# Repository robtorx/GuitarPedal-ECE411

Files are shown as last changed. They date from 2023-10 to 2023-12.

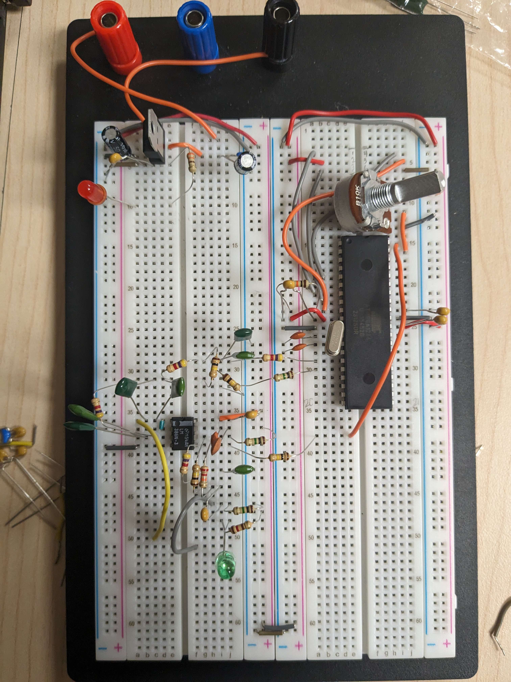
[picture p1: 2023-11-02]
Breadboard_Prototype_WIP.jpg

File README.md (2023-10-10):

# coolproject
ECE 411 - Fall 2023 - Team 12

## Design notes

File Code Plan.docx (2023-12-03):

High Level

Basic Operation: The program uses TIMER1 interrupts to initiate each ADC conversion manually, which allows for better control over the sample rate.

Setup Pins

- Set PD1 and PD2 as output pins.
- Set PA0 and PA1 as input pins.

Setup Timer1

- Initialize TIMER1 counter TCNT1 to 0x00.
- Set TIMER1 prescaler to 1 so TIMER1 = 16 MHz.
  - Frequency of timer interrupt = system clock frequency/(prescaler * compare match register value + 1)
- Timer operates in phase correct, PWM mode. TOP value is stored in ICR1, since OCR1A/B are used to control PWM output pins.
  - Set WGM13 to 1, WGM12 to 0, WGM11 to 1, WGM10 to 0.
- Maximize PWM frequency.
  - PWM frequency = timer
  - Write 0xFF to ICR1L.
  - Write 0xFF, shifted 8 bits to ICR1H.

Setup ADC

- Use AVCC as reference voltage -> Write 1 to ADMUX.REFS
- Left aligned for 8 bit resolution: write 1 to ADMUX.ADLAR
- Prescaler = 128 for 16 MHz clock
  - ADC operates from 50 KHz to 200 KHz to get maximum resolution
  - 16 MHz/128 = 125 KHz ADC frequency
  - Write 0x111 to ADCSRA.ADPS
- Initialize ADMUX.MUX to channel 0 (pin ADC0)
  - This will change periodically to channel 1 in order to read the potentiometer.
- IF FREE RUNNING MODE:
  - Enable ADC conversion complete interrupt.
    - Set ADCSRA.ADIE to 1.
  - Enable auto trigger.
    - Write 1 to ADCSRA.ADATE
- Enable ADC.
  - Set power reduction ADC bit (PRR.PRADC) to 0
  - Write 1 to ADCSR.ADEN.
    - Note: Takes 25 ADC clock cycles to initialize first conversion. After that, further conversions take 13 ADC clock cycles (13.5 for auto triggered conversions).
- Enable global interrupts.
- Start a single conversion.
  - Set start conversion bit to 1 in ADCSRA.ADCS.

Change Channels Function

- If ADMUX.MUX = 0 (ADC0 currently active)
  - Set ADMUX.MUX to 1.
- If ADMUX.MUX = 1
  - Set ADMUX.MUX to 0.

Interrupt Service: TIMER1

- Increment counter.
- If counter = n:
  - Switch ADC channels.
  - Reset counter = 0.
- If counter = 0:
  - Switch ADC channels
- Initiate ADC conversion.

Interrupt Service: ADC Complete

- POTENTIOMETER LOGIC: If counter = n (n to be found experimentally)
  - Read ADCH into POT. Leave ADCin unchanged.
  - Call change channels function again.
  - Reset counter = 0.
- Map upper and lower threshholds based on potentiometer value.
- Map input values to amplified equivalents.
- If (ADC value >= upper threshold)
  - Set output value = upper threshold
- If (ADC value <= lower threshold)
  - Set output value = lower threshold
- POTENTIOMETER LOGIC: If (++counter=n)
  - Call change channels function so next ADC interrupt will be for channel 1.
- Convert ADC_high and ADC_low into 16 bit value.
  - Write combined value to OCR1A/B.

https://onlinedocs.microchip.com/pr/GUID-F670183D-C025-46C7-B7F5-9BAD389BF43F-en-US-3/index.html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

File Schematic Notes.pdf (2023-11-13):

Input Buffer Stage
R2 and R3 form a non-inverting amplifier circuit that amplifies the guitar level (100-400 mV) to acceptable ADC level (5 V). This means the circuit gain has to be at most 5V/0.1V = 50 and at least 5V/0.4V = 12.5.
- A = 1 +

R2
R3 = 1 +

100k
4.7k = 22. 277
R2 and C8 form a low pass filter that allows all frequencies below 4823 Hz to pass. Additionally, R3 and C9 form a high pass filter that allows all frequencies above 34 Hz to pass. C7, R5 and R6 form another high pass filter that eliminates the DC component from the signal. These filters cut out unnecessary noise and frequencies that are harsh when amplified.
- f = 1/2πRC
R4 essentially becomes the input impedance of the signal chain, which is typically 1M Ohms for guitar pedals.

Output Buffer
2 PWM pins are used in order to double the bitrate of the output signal. If only one PWM signal is outputted by the ATMega, the output amplifier defaults to being a buffer.

Resistors R9, R10, capacitors C14, and C11 all form a 3rd order Sallen & Key low pass filter with a cutoff frequency at 5131 Hz.
- f = 1/(2π * R
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
Capacitor C12 eliminates any DC offset before outputting the final, processed signal.

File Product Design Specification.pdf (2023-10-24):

### Team 12 Product Design Specifications

Oct 18, 2023

Executive Summary with Concept of Operations
A guitar pedal takes an input signal from a guitar and modifies it with an effect before passing it on to the output chain (could be an amplifier). It’s used by guitarists to achieve different tones and effects. Our pedal is specifically a distortion pedal, which increases the signal’s gain to produce a gritty tone. The user is able to turn on and change the level of distortion using a foot pedal (button) and knobs.

Who are the intended customers / users?
Although we are designing this product with electric guitarists in mind, anyone who plays an instrument with a line signal could use this pedal. We are targeting the product towards those hoping to achieve different sounds or enhance their performance.

What is the competition? Why is your product different?
The competition is all custom guitar pedals. This includes companies like BOSS, Donner, Ibanez and Line 6. Additionally, there is a wide market and scene for smaller indie pedal producers, as well as DIY hobbyists.

In theory, what sets this pedal apart is the fact that it’s programmable, as opposed to most typical, purely analog pedals. This means you could add, layer or otherwise change the effect via software, allowing a variety of sounds within the same product. That said, we are choosing to focus on a distortion effect as our minimal requirement.

What price do you think you can sell this for, and why? (keep it short, we're engineers, not marketing researchers)
The cheapest end of popular pedals on the market are around $60, so we aim to keep our model below that, at around $40-$50 per unit. Having a relatively lower price means customers are more likely to risk buying a product from an unknown manufacturer like our team, over a more reputable brand like BOSS. This is our goal for at least the minimal distortion pedal; Should we achieve the programmable multi-effect goal, we could charge more for the novelty.

Product Requirements
Must:
- Must distort the input signal in some way.
- Must be able to be toggled on/off.
- Must be durable enough to be operated by foot.
- Must not harm the user.
- Must be able to vary the level of the distortion effect. Should:
- Should not introduce significant noise when bypassed.

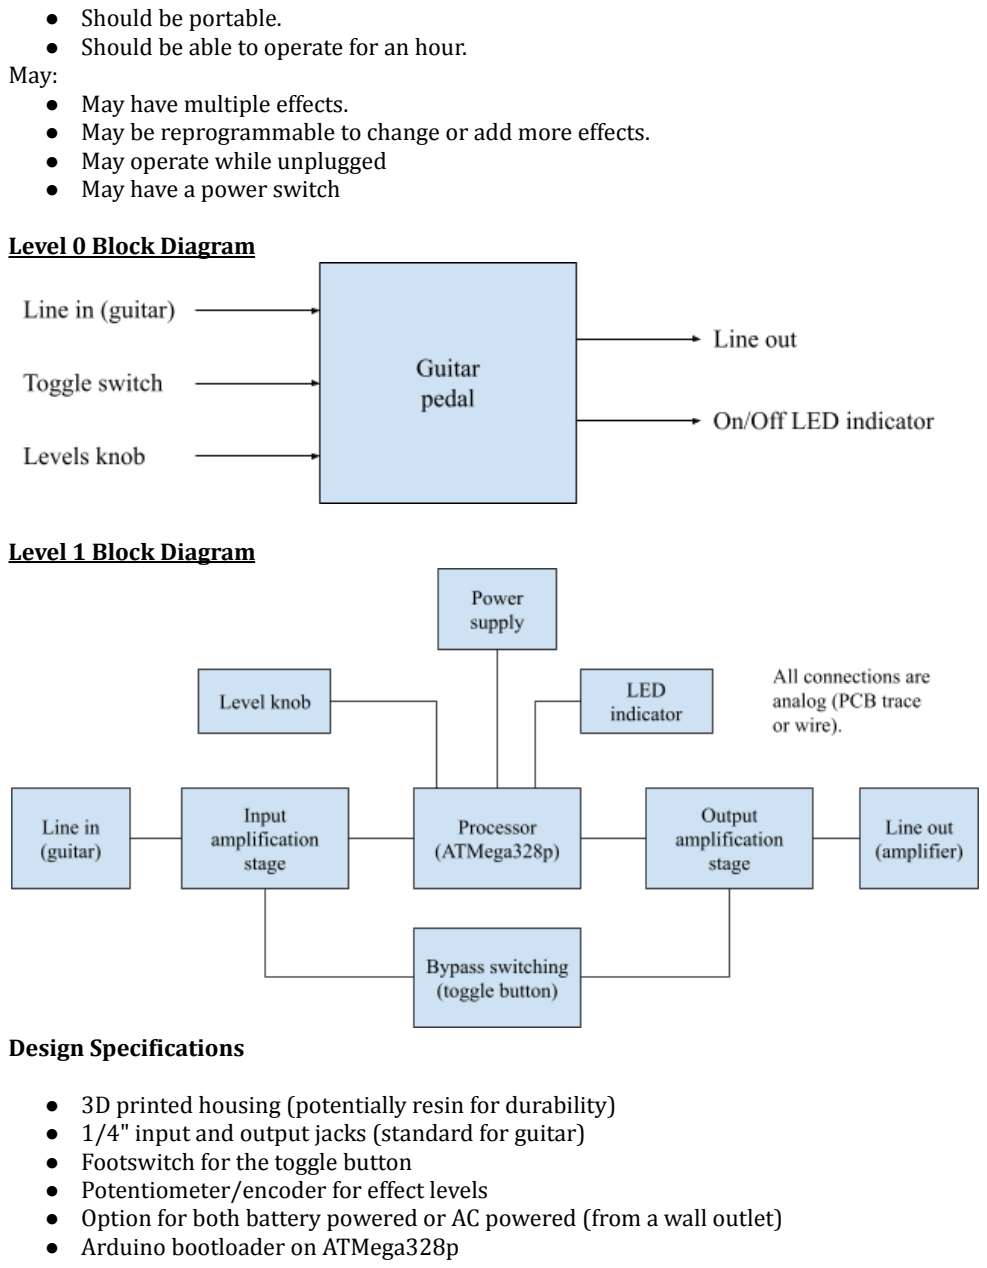
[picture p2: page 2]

- Should be portable.
- Should be able to operate for an hour.
May:
- May have multiple effects.
- May be reprogrammable to change or add more effects.
- May operate while unplugged
- May have a power switch

Level 0 Block Diagram

Level 1 Block Diagram

Design Specifications

- 3D printed housing (potentially resin for durability)
- 1/4" input and output jacks (standard for guitar)
- Footswitch for the toggle button
- Potentiometer/encoder for effect levels
- Option for both battery powered or AC powered (from a wall outlet)
- Arduino bootloader on ATMega328p

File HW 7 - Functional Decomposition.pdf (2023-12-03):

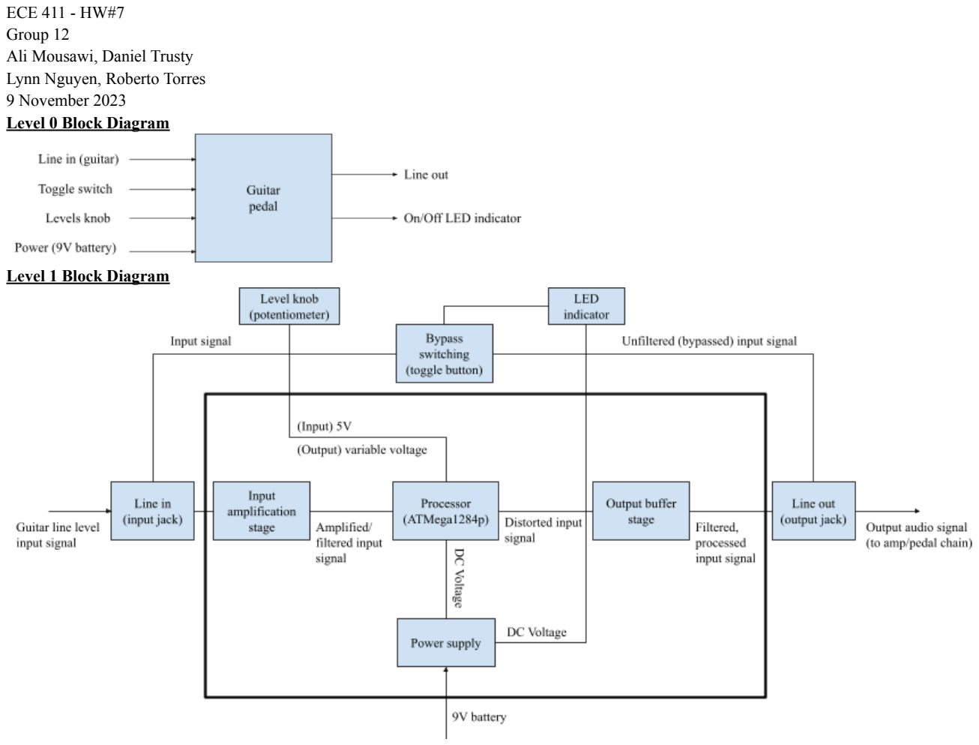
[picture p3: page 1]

ECE 411 - HW#7
Group 12
Ali Mousawi, Daniel Trusty Lynn Nguyen, Roberto Torres 9 November 2023
Level 0 Block Diagram

Level 1 Block Diagram

Submodules L1
Line In

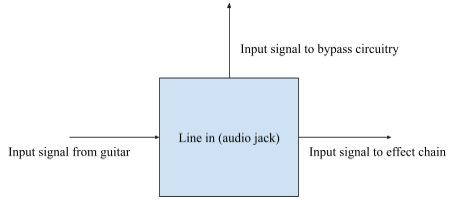
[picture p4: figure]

Module | Line in (audio jack)
Inputs | Audio signal from guitar (100 - 400 mV standard)
Outputs | Input signal to effect circuitry, input signal to bypass circuitry (100 - 400 mV)
Functionality | Accepts external audio source (from guitar)

Bypass Switch

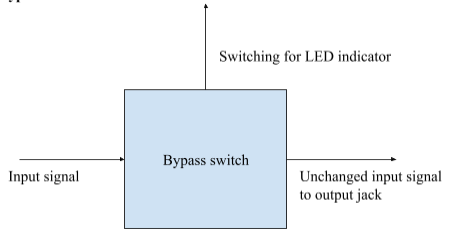
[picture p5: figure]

Module | Bypass circuitry
Inputs | Input signal from input jack
Outputs | Unprocessed input signal to output jack, switching circuitry for LED indicator
Functionality | Allows user the option of toggling the pedal effect, part of and controls user interface (LED)

LED indicator

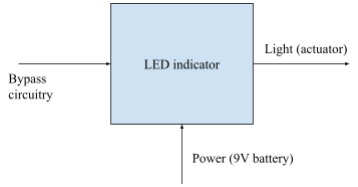
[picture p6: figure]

Module | LED indicator
Inputs | Bypass circuitry, power (9V battery)
Outputs | Light indication
Functionality | User interface, allows user to know if effect is on or off

Levels knob

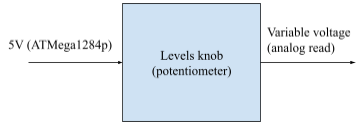
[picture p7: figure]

Module | Levels knob
Inputs | 5V (ATMega1284p)
Outputs | Variable voltage to ATMega1284p analog read
Functionality | User interface, used as a voltage sensor translated to variable levels in effect

Input amplification stage

Module | Input amplification stage
Inputs | Input audio signal (100-400 mV)
Outputs | Filtered/amplified audio signal (5 V)
Functionality | Amplifies signal to ATMega1284p ADC pin levels, cuts unnecessary noise through filtering

Processor

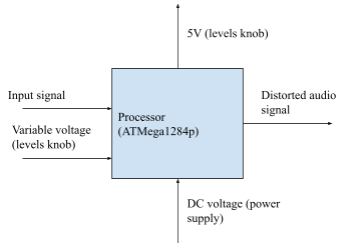
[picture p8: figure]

Module | Input amplification stage
Inputs | Input audio signal (5 V), variable voltage (from levels knob, analog read)
Outputs | Distorted audio signal, 5V for levels knob
Functionality | Performs digital processing on audio signal based on user inputs

Output buffer stage

Module | Output buffer stage
Inputs | Distorted audio signal (5 V)
Outputs | Filtered, distorted signal
Functionality | Further filters distorted signal to prepare for output

Line out

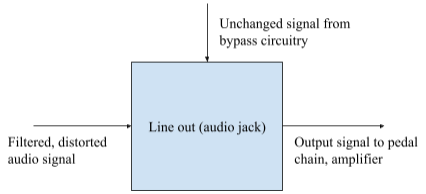
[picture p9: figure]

Module | Line in (audio jack)
Inputs | (Only one transmitting at once) unchanged signal from bypass circuitry, filtered/distorted audio signal
Outputs | Output signal to pedal chain or amplifier
Functionality | Transmits audio to external actuator (amplifier, pedal chain)

Line out

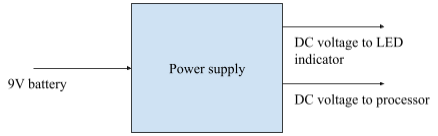
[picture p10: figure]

Module | Power supply
Inputs | 9V battery
Outputs | DC voltages
Functionality | Provides regulated power to all circuitry

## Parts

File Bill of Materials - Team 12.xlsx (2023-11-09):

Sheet: ECE411 BOM Template
Bill Of Materials for: T12
Last modified: 8 Nov 2023
PCB version: [PCB VERSION #]
BOM revision: [BOM REVISION #] |  | P/NP | = Place/Not Place (components marked NP are not stuffed on the board)
Cnt | Part References | P/NP | Mfg | Mfg PN | Description | Dist | Dist Part Number | Cost Ea. | Cost Total
1 | U1 | P | Microchip | ATmega1284-AU-ND | IC MCU 8BIT 128KB FLASH 44TQFP | Digi-Key | ATMEGA1284-AU-ND | $6.30 | $6.30
1 | U2 | P | ST | L7805ABV | IC Linear Voltage Regulator 5V 1.5A TO220AB | Digi-Key | 497-2947-5-ND | $0.75 | $0.75
1 | U3 | P | TI | TL972IDR | IC OPAMP GP 2 CIRCUIT 8SOIC | Digi-Key | 296-22842-1-ND - (CT) | $0.80 | $0.80
1 | Y1 | P | CTS Electronic Components | ATS16A | 16MHz 20pF Crystal Oscillator | Mouser | 774-ATS16A | $0.45 | $0.45
1 | RV1 | P | Swpeet | N/A | 10k Single Linear Rotary Potentiometer 3T WH148 and Knob | Amazon | B07ZKJVZ53 | $0.60 | $0.60
2 | J1, J2 | P | Neutrik | NMJ6HCD2 | 1/4" TRS Audio Jack | Mouser | 550-22302 | $2.29 | $4.58
1 | SW1 | P | DaierTek | KCD1-101 | SPST 2PIN Rocker Switch ON/OFF | Amazon | B07S2QJKTX | $0.80 | $0.80
1 | SW2 | P | ESUPPORT | CXGTS01A | 3PDT 9 Pins Metal Foot Switch True Bypass | Amazon | B012CF181K | $2.58 | $2.58
1 | D1 | P | Generic | N/A | RED LED 5MM | Digi-Key | 160-1827-ND | $0.07 | $0.07
1 | D2 | P | Generic | N/A | GREEN LED 5MM | Digi-Key | 1N4148FS-ND | $0.03 | $0.03
2 | C1, C2 | P | Walfront | N/A | 10uf SMD Electrolytic Capacitor | Amazon | ‎ B0793N3YJR | $0.07 | $0.14
4 | C10, C11, C12, C14 | P | MCIGICM | N/A | 6.8nF Ceramic Capacitor 1206 SMD | Amazon | B06XDHC93D | $0.03 | $0.12
1 | C3 | P | MCIGICM | N/A | 0.33uf Ceramic Capacitor 1206 SMD | Amazon | B06XDHC93D | $0.03 | $0.03
6 | C4, C7, C13, C15, C16, C17 | P | MCIGICM | N/A | 100NF 104M Y5V 50V ± 20% | Amazon | B06XDHC93D | $0.03 | $0.18
2 | C5, C6 | P | MCIGICM | N/A | 22PF 220J COG 50V ± 5% | Amazon | B06XDHC93D | $0.03 | $0.06
1 | C8 | P | MCIGICM | N/A | 270pf Ceramic Capacitor 1206 SMD | Amazon | B06XDHC93D | $0.03 | $0.03
1 | C9 | P | Walfront | N/A | 1uf SMD Electrolytic Capacitor | Amazon | ‎ B0793N3YJR | $0.07 | $0.07
1 | R1 | P | Chanzon | DZ-TPDZ1206B1-TC60-1200 | 330R Resistor 1206 SMD 1/4W 0.25W ±1% | Amazon | B08RYMYWG9 | $0.01 | $0.01
1 | R2 | P | Chanzon | DZ-TPDZ1206B1-TC60-1200 | 100k Resistor 1206 SMD 1/4W 0.25W ±1% | Amazon | B08RYMYWG9 | $0.01 | $0.01
4 | R3, R7, R9, R10 | P | Chanzon | DZ-TPDZ1206B1-TC60-1200 | 4.7k Resistor 1206 SMD 1/4W 0.25W ±1% | Amazon | B08RYMYWG9 | $0.01 | $0.04
2 | R4, R6 | P | Chanzon | DZ-TPDZ1206B1-TC60-1200 | 1M Resistor 1206 SMD 1/4W 0.25W ±1% | Amazon | B08RYMYWG9 | $0.01 | $0.02
1 | R5 | P | Chanzon | DZ-TPDZ1206B1-TC60-1200 | 18k Resistor 1206 SMD 1/4W 0.25W ±1% | Amazon | B08RYMYWG9 | $0.01 | $0.01
1 | R8 | P | Chanzon | DZ-TPDZ1206B1-TC60-1200 | 1M2 Resistor 1206 SMD 1/4W 0.25W ±1% | Amazon | B08RYMYWG9 | $0.01 | $0.01
1 | R11 | P | Chanzon | DZ-TPDZ1206B1-TC60-1200 | 120R Resistor 1206 SMD 1/4W 0.25W ±1% | Amazon | B08RYMYWG9 | $0.01 | $0.01
1 | R12 | P | Chanzon | DZ-TPDZ1206B1-TC60-1200 | 10k Resistor 1206 SMD 1/4W 0.25W ±1% | Amazon | B08RYMYWG9 | $0.01 | $0.01
1 | BT1 | NP | Generic | N/A | 9V Battery | Amazon | N/A | $1.50 | $1.50
1 | NA | P | Generic | N/A | 9V Battery Connector | Amazon | N/A | $0.50 | $0.50
6 | NA | P | Generic | N/A | Breakable Headers 2.54mm | Amazon | N/A | $0.01 | $0.03
 |  |  |  |  |  |  |  | TOTAL: | $19.74
VERSION INFO
Rev | Date | Notes
1 | 2023-11-09 | Inital BOM

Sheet: Copy of ECE411 BOM Template
Bill Of Materials for: T12
Last modified: 8 Nov 2023
PCB version: [PCB VERSION #]
BOM revision: [BOM REVISION #] |  | P/NP | = Place/Not Place (components marked NP are not stuffed on the board)
Cnt | Part References | P/NP | Mfg | Mfg PN | Description | Dist | Dist Part Number | Cost Ea. | Cost Total | Shipping Cost | Purchase Links
1 | U1 | P | Microchip | ATmega1284-AU-ND | IC MCU 8BIT 128KB FLASH 44TQFP | Digi-Key | ATMEGA1284-AU-ND | $6.30 | $6.30 | 6.99 | https://www.digikey.com/en/products/detail/microchip-technology/ATMEGA1284-AU/2271240
1 | U2 | P | ST | L7805ABV | IC Linear Voltage Regulator 5V 1.5A TO220AB | Digi-Key | 497-2947-5-ND | $0.75 | $0.75 | EPL | https://www.digikey.com/en/products/detail/stmicroelectronics/L7805ABV/634711
1 | U3 | P | TI | TL972IDR | IC OPAMP GP 2 CIRCUIT 8SOIC | Digi-Key | 296-22842-1-ND - (CT) | $0.80 | $0.80 | inc | https://www.digikey.com/en/products/detail/texas-instruments/TL972IDR/1739871
1 | Y1 | P | CTS Electronic Components | ATS16A | 16MHz 20pF Crystal Oscillator | Mouser | 774-ATS16A | $0.45 | $0.45 | inc | https://www.mouser.com/ProductDetail/774-ATS16A
1 | RV1 | P | Swpeet | N/A | 10k Single Linear Rotary Potentiometer 3T WH148 and Knob | Amazon | B07ZKJVZ53 | $0.60 | $0.60 | X | https://www.amazon.com/dp/B07ZKJVZ53
2 | J1, J2 | P | Neutrik | NMJ6HCD2 | 1/4" TRS Audio Jack | Mouser | 550-22302 | $2.29 | $4.58 | 7.99 | https://www.mouser.com/ProductDetail/550-22302
1 | SW1 | P | DaierTek | KCD1-101 | SPST 2PIN Rocker Switch ON/OFF | Amazon | B07S2QJKTX | $0.80 | $0.80 | X | https://www.amazon.com/dp/B07S2QJKTX
1 | SW2 | P | ESUPPORT | CXGTS01A | 3PDT 9 Pins Metal Foot Switch True Bypass | Amazon | B012CF181K | $2.58 | $2.58 |  | https://www.amazon.com/dp/B012CF181K
1 | D1 | P | Generic | N/A | RED LED 5MM | Digi-Key | 160-1827-ND | $0.07 | $0.07
1 | D2 | P | Generic | N/A | GREEN LED 5MM | Digi-Key | 1N4148FS-ND | $0.03 | $0.03
2 | C1, C2 | P | Walfront | N/A | 10uf SMD Electrolytic Capacitor | Amazon | ‎ B0793N3YJR | $0.07 | $0.14
4 | C10, C11, C12, C14 | P | MCIGICM | N/A | 6.8nF Ceramic Capacitor 1206 SMD | Amazon | B06XDHC93D | $0.03 | $0.12
1 | C3 | P | MCIGICM | N/A | 0.33uf Ceramic Capacitor 1206 SMD | Amazon | B06XDHC93D | $0.03 | $0.03
6 | C4, C7, C13, C15, C16, C17 | P | MCIGICM | N/A | 100NF 104M Y5V 50V ± 20% | Amazon | B06XDHC93D | $0.03 | $0.18
2 | C5, C6 | P | MCIGICM | N/A | 22PF 220J COG 50V ± 5% | Amazon | B06XDHC93D | $0.03 | $0.06
1 | C8 | P | MCIGICM | N/A | 270pf Ceramic Capacitor 1206 SMD | Amazon | B06XDHC93D | $0.03 | $0.03
1 | C9 | P | Walfront | N/A | 1uf SMD Electrolytic Capacitor | Amazon | ‎ B0793N3YJR | $0.07 | $0.07
1 | R1 | P | Chanzon | DZ-TPDZ1206B1-TC60-1200 | 330R Resistor 1206 SMD 1/4W 0.25W ±1% | Amazon | B08RYMYWG9 | $0.01 | $0.01
1 | R2 | P | Chanzon | DZ-TPDZ1206B1-TC60-1200 | 100k Resistor 1206 SMD 1/4W 0.25W ±1% | Amazon | B08RYMYWG9 | $0.01 | $0.01
4 | R3, R7, R9, R10 | P | Chanzon | DZ-TPDZ1206B1-TC60-1200 | 4.7k Resistor 1206 SMD 1/4W 0.25W ±1% | Amazon | B08RYMYWG9 | $0.01 | $0.04
2 | R4, R6 | P | Chanzon | DZ-TPDZ1206B1-TC60-1200 | 1M Resistor 1206 SMD 1/4W 0.25W ±1% | Amazon | B08RYMYWG9 | $0.01 | $0.02
1 | R5 | P | Chanzon | DZ-TPDZ1206B1-TC60-1200 | 18k Resistor 1206 SMD 1/4W 0.25W ±1% | Amazon | B08RYMYWG9 | $0.01 | $0.01
1 | R8 | P | Chanzon | DZ-TPDZ1206B1-TC60-1200 | 1M2 Resistor 1206 SMD 1/4W 0.25W ±1% | Amazon | B08RYMYWG9 | $0.01 | $0.01
1 | R11 | P | Chanzon | DZ-TPDZ1206B1-TC60-1200 | 120R Resistor 1206 SMD 1/4W 0.25W ±1% | Amazon | B08RYMYWG9 | $0.01 | $0.01
1 | R12 | P | Chanzon | DZ-TPDZ1206B1-TC60-1200 | 10k Resistor 1206 SMD 1/4W 0.25W ±1% | Amazon | B08RYMYWG9 | $0.01 | $0.01
1 | BT1 | NP | Generic | N/A | 9V Battery | Amazon | N/A | $1.50 | $1.50
1 | NA | P | Generic | N/A | 9V Battery Connector | Amazon | N/A | $0.50 | $0.50
6 | NA | P | Generic | N/A | Breakable Headers 2.54mm | Amazon | N/A | $0.01 | $0.03
 |  |  |  |  |  |  |  | TOTAL: | $19.74
VERSION INFO
Rev | Date | Notes
1 | 2023-11-09 | Inital BOM

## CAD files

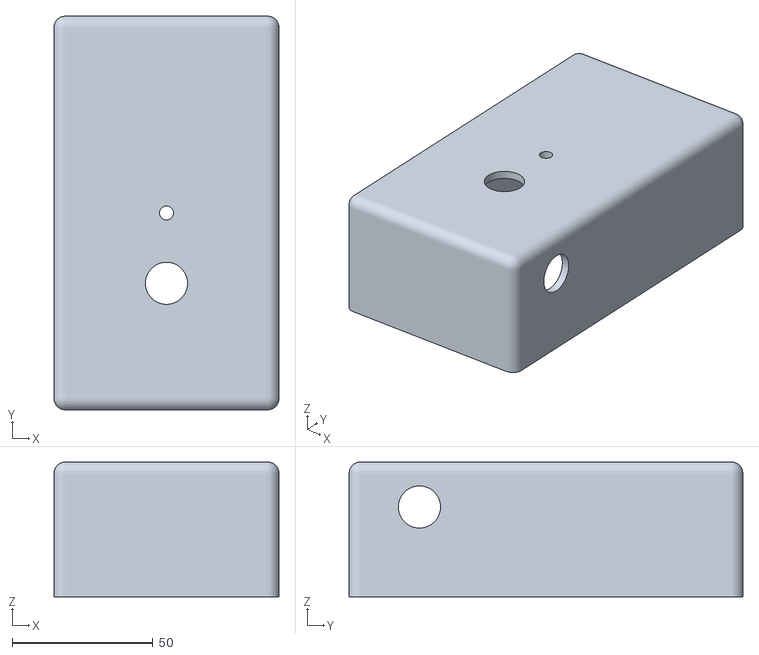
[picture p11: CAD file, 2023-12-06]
Fusion files/Upper housing v9.stl
80.0 x 140.0 x 48.0

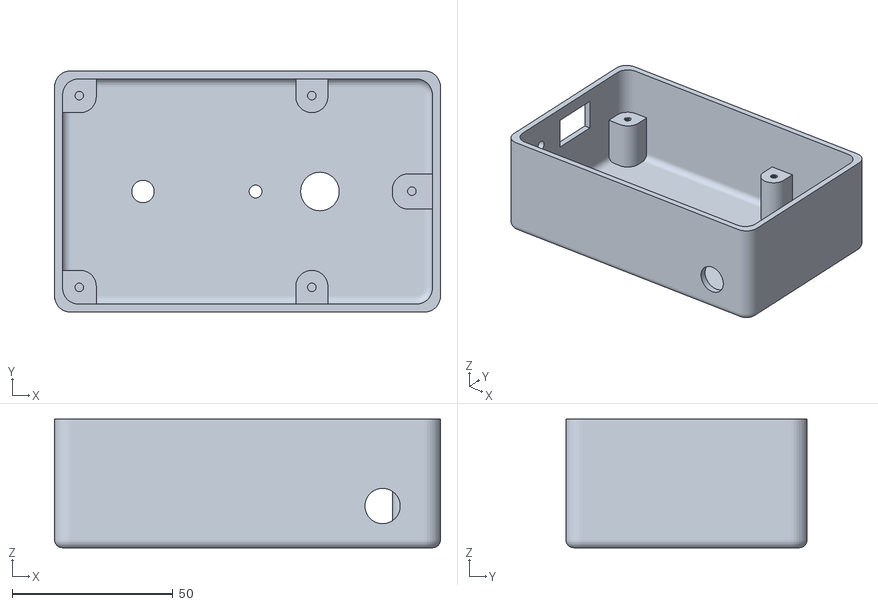
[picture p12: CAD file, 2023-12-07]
STL Files/UpperHousing v1.stl
120.0 x 75.0 x 40.0

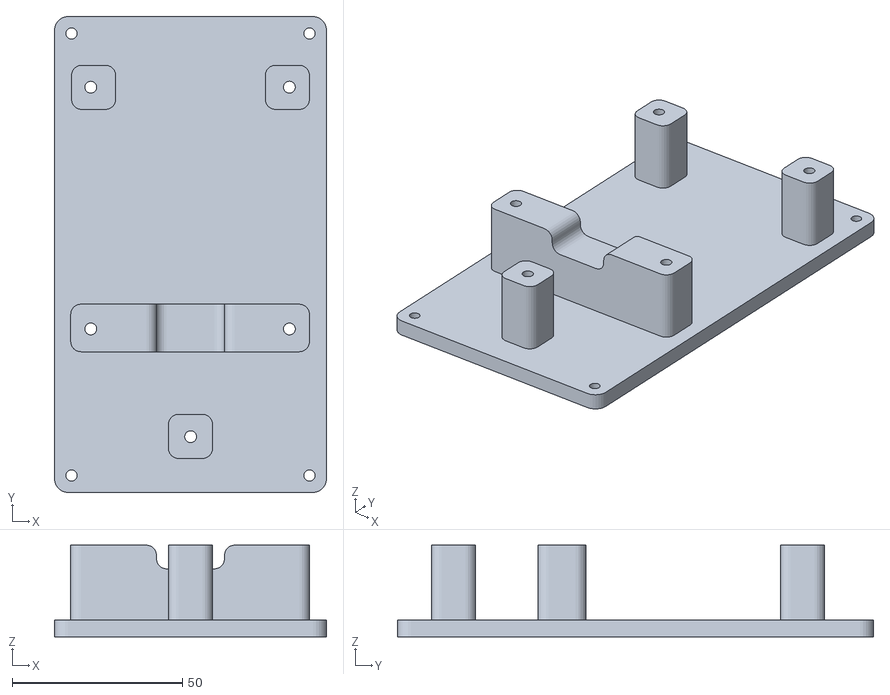
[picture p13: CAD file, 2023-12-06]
Fusion files/Bottom Housing v4.stl
80.0 x 140.0 x 27.0

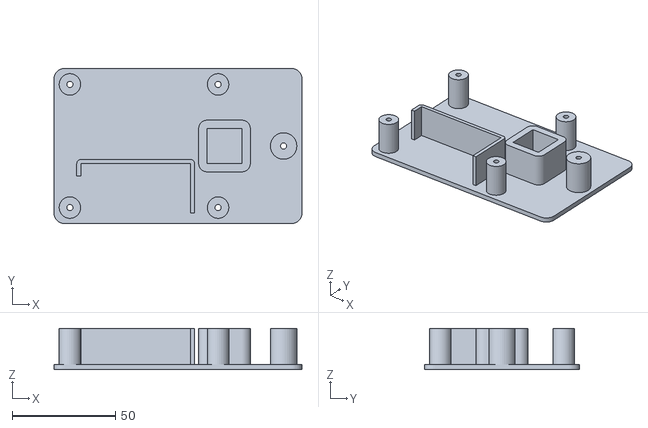
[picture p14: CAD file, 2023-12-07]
STL Files/BottomHousing v2.stl
120.0 x 75.0 x 20.0

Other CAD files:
Fusion files/Bottom Housing v4.f3d
Fusion files/Upper housing v9.f3d

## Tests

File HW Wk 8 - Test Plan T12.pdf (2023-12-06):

Part 1: Comprehensive hierarchical test plan.

1. Unit Tests
- Test Power Supply Stability: Ensure the power supply consistently outputs a stable voltage (9V to 5V).
- Test LED Functionality: Verify both red and green LEDs light up and match footswitch height.
- Test Footswitch Bypass: Check the footswitch bypass functionality for continuity and operational integrity.
2. Verification Tests
- Verify Audio Signal Integrity: Test if the pedal correctly processes and outputs the audio signal without unwanted alterations.
- Verify Bypass Signal Path: Ensure the audio signal bypasses the effects when the pedal is in bypass mode.
- Verify PCB Component Placement: Confirm that all components, including soldered ones, are placed and function as intended.
3. Validation Tests
- Validate System Functionality with Different Batteries: Confirm that the system functions correctly with different types of 9V batteries, including the 1604A 9V battery.
- Validate Response to Code Changes: Test the system's response to the new code developments, especially the bypass signal issue.

Part 2: Detailed Test Cases.

Test Author: Lynn, Ali, Roberto, Daniel
Test Case Name: | Power Supply Stability Test (Unit Test) | Test ID #: | 001
Description: | Testing the stability and accuracy of voltage regulation from 9V to 5V in the system. | Type: | □ white box □black box □ ________

Tester Information
| Name of Tester: | | Date: | Nov 27
| HW/SW Version: | 1.0 | Time: | 11 pm
| Setup: | Standard lab power supply, multimeter, oscilloscope.
S T E | Action | Expected Result | P A S | F A I | N / A | Comments

P | | | S | L
1 | Apply 9V input from the power supply | Stable output of 5V
2 | Vary input voltage slightly (± 1V) | Output voltage remains stable at 5V
3 | Check for ripple voltage using an oscilloscope | Minimal ripple voltage
4
5
6
7
8
9
| Overall test result:

Test Author:

Test Case Name: | User Interface Testing | Test ID #: | 002
Description: | | Type: | □ white box □ black box □ _____________

Tester Information

| Name of Tester: | | Date:
| HW/SW Version: | 1.0 | Time:
| Setup:
T E S T | INPUTS | EXPECTED OUTPUTS | P A S S | F A I L | N / A | Comments
1 | Power Off | No signal All LEDs off
2 | Bypass Switch | Clean output guitar signal Green LED off
3 | Effect on | Audibly distorted guitar signal Green LED on

4

| Overall test result:

Test Author:
Test Case Name: | Potentiometer Response and Accuracy Test | Test ID #: | 003
Description: | Testing the potentiometer's responsiveness and accuracy in controlling the pedal's parameters. | Type: | □ white box □black box □ ________

Tester Information
| Name of Tester: | | Date: | 29 Nov
| HW/SW Version: | 1.0 | Time: | 10 pm
| Setup:
S T E P | Action | Expected Result | P A S S | F A I L | N / A | Comments
1 | Rotate the potentiometer from minimum to maximum. | Smooth increase in the parameter value (e.g., gain, tone) with no sudden jumps or inconsistencies.
2 | Set the potentiometer to a mid-point and measure the output. | The parameter value corresponds to the mid-range as per design specifications.
3 | Connect an audio source and rotate the potentiometer while playing. | Audible changes in the sound effect correlating with the potentiometer's position.
4 | Use an oscilloscope or multimeter to measure the voltage variation across the potentiometer while adjusting. | Voltage changes proportionally with the potentiometer's rotation.

5
6
7
8
9
| Overall test result:

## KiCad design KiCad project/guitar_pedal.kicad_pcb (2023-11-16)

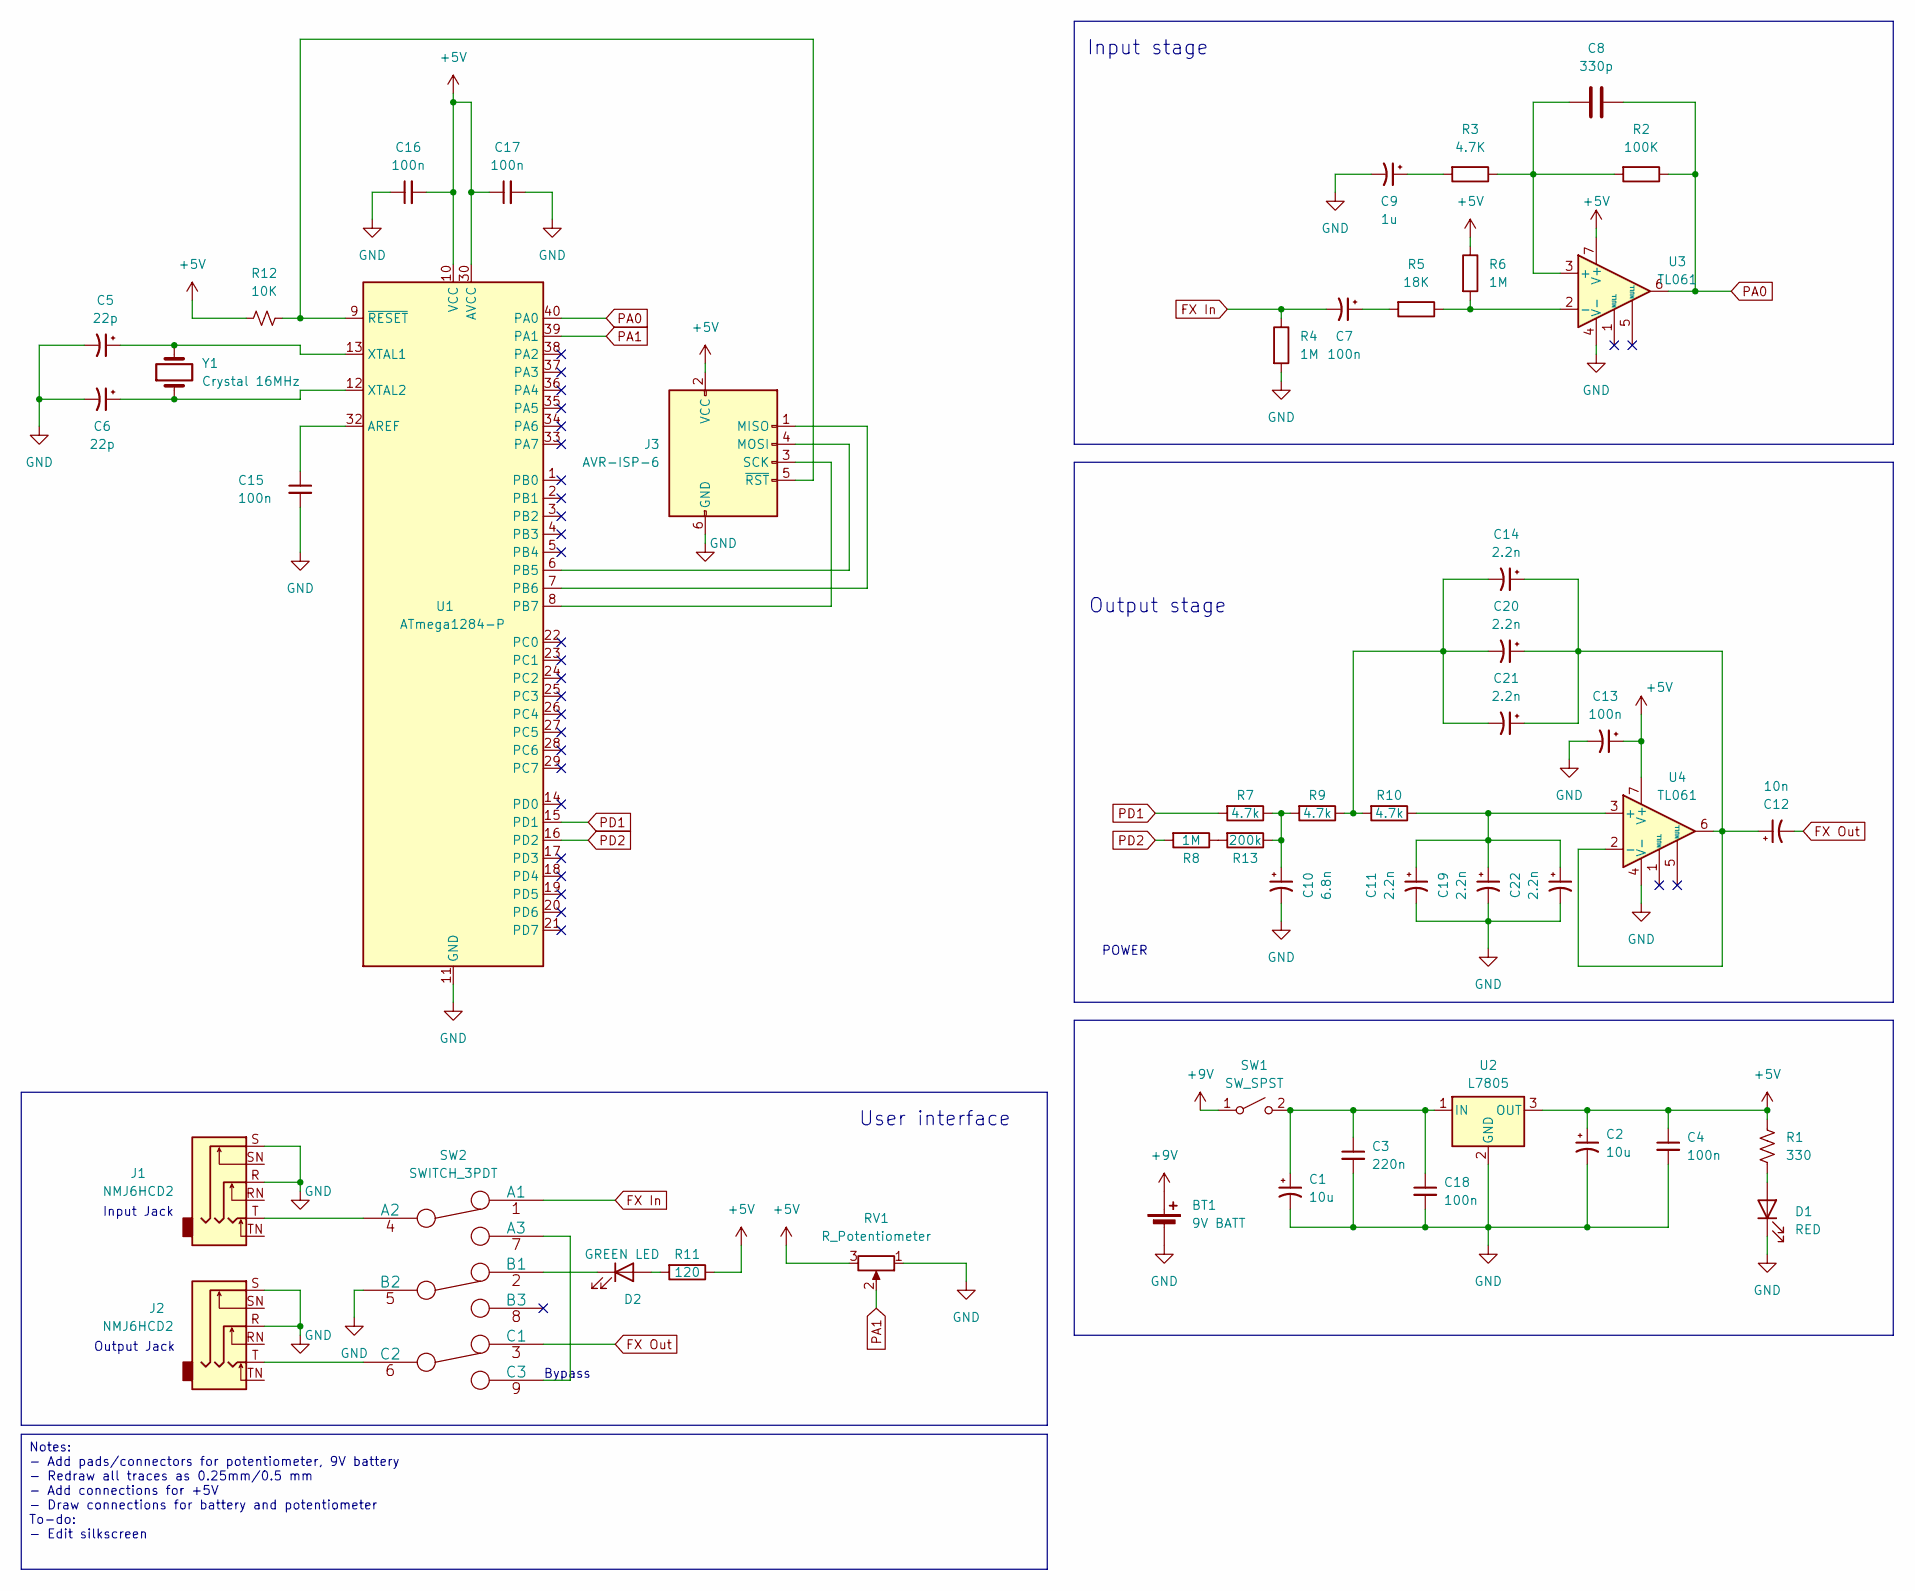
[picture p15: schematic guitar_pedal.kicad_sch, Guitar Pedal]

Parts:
BT1: 9V BATT; PinHeader_1x02_P2.54mm_Vertical
C1, C2: 10u; C_1206_3216Metric
C3: 220n; C_1206_3216Metric
C4, C7, C13, C15, C16, C17, C18: 100n; C_1206_3216Metric
C5, C6: 22p; C_1206_3216Metric
C8: 330p; C_1206_3216Metric
C9: 1u; C_1206_3216Metric
C10: 6.8n; C_1206_3216Metric
C11, C14, C19, C20, C21, C22: 2.2n; C_1206_3216Metric
C12: 10n; C_1206_3216Metric
D1: RED; LED_D3.0mm
D2: GREEN LED; LED_D3.0mm
J1, J2: NMJ6HCD2; Jack_6.35mm_Neutrik_NMJ6HCD2_Horizontal
J3: AVR-ISP-6
R1: 330; R_1206_3216Metric
R2: 100K; R_1206_3216Metric
R3: 4.7K; R_1206_3216Metric
R4, R6, R8: 1M; R_1206_3216Metric
R5: 18K; R_1206_3216Metric
R7, R9, R10: 4.7k; R_1206_3216Metric
R11: 120; R_1206_3216Metric
R12: 10K; R_1206_3216Metric
R13: 200k; R_1206_3216Metric
RV1: R_Potentiometer; PinHeader_1x03_P2.54mm_Vertical
SW1: SW_SPST; PinHeader_1x02_P2.54mm_Vertical
SW2: SWITCH_3PDT; 3PDT
U1: ATmega1284-P; TQFP-44_10x10mm_P0.8mm
U2: L7805; TO-220-3_Vertical
U3, U4: TL061; SOIC-8-1EP_3.9x4.9mm_P1.27mm_EP2.29x3mm
Y1: Crystal 16MHz; Crystal_HC49-U_Vertical

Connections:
+5V: C2.1, C4.1, C13.1, C16.2, C17.1, J3.2 (VCC), R1.1, R6.1, R11.1, R12.1, RV1.3, U1.10 (VCC), U1.30 (AVCC), U2.3 (OUT), U3.7 (V+), U4.7 (V+)
+9V: BT1.1 (+), SW1.1 (A)
FX In: C7.2, R4.1, SW2.1 (A1)
FX Out: C12.2, SW2.3 (C1)
GND: BT1.2 (-), C1.2, C2.2, C3.2, C4.2, C5.2, C6.2, C9.2, C10.2, C11.2, C13.2, C15.2, C16.1, C17.2, C18.2, C19.2, C22.2, D1.1 (K), J1.R, J1.S, J2.R, J2.S, J3.6 (GND), R4.2, RV1.1, SW2.5 (B2), U1.11 (GND), U1.31 (GND), U2.2 (GND), U3.4 (V-), U4.4 (V-)
unnamed: C7.1, R5.2
unnamed: C9.1, R3.2
unnamed: C10.1, R7.1, R9.2, R13.1
unnamed: C14.2, C20.2, C21.2, R9.1, R10.2
unnamed: D1.2 (A), R1.2
unnamed: D2.2 (A), R11.2
unnamed: D2.1 (K), SW2.2 (B1)
unnamed: J3.1 (MISO), U1.7 (PB6)
unnamed: J3.4 (MOSI), U1.6 (PB5)
unnamed: J3.3 (SCK), U1.8 (PB7)
unnamed: J3.5 (~RST), R12.2, U1.9 (~RESET)
unnamed: R8.1, R13.2
unnamed: C1.1, C3.1, C18.1, SW1.2 (B), U2.1 (IN)
unnamed: J1.T, SW2.4 (A2)
unnamed: SW2.7 (A3), SW2.9 (C3)
unnamed: J2.T, SW2.6 (C2)
unnamed: C15.1, U1.32 (AREF)
unnamed: C5.1, U1.13 (XTAL1), Y1.2
unnamed: C6.1, U1.12 (XTAL2), Y1.1
unnamed: C8.1, R2.2, R3.1, U3.3 (+)
unnamed: R5.1, R6.2, U3.2 (-)
unnamed: C11.1, C19.1, C22.1, R10.1, U4.3 (+)
unnamed: C12.1, C14.1, C20.1, C21.1, U4.2 (-), U4.6
PA0: C8.2, R2.1, U1.40 (PA0), U3.6
PA1: RV1.2, U1.39 (PA1)
PD1: R7.2, U1.15 (PD1)
PD2: R8.2, U1.16 (PD2)

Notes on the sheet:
Notes: - Add pads/connectors for potentiometer, 9V battery - Redraw all traces as 0.25mm/0.5 mm - Add connections for +5V - Draw connections for battery and potentiometer To-do: - Edit silkscreen
Output stage
Bypass
Input stage
User interface
POWER
Output Jack
Input Jack

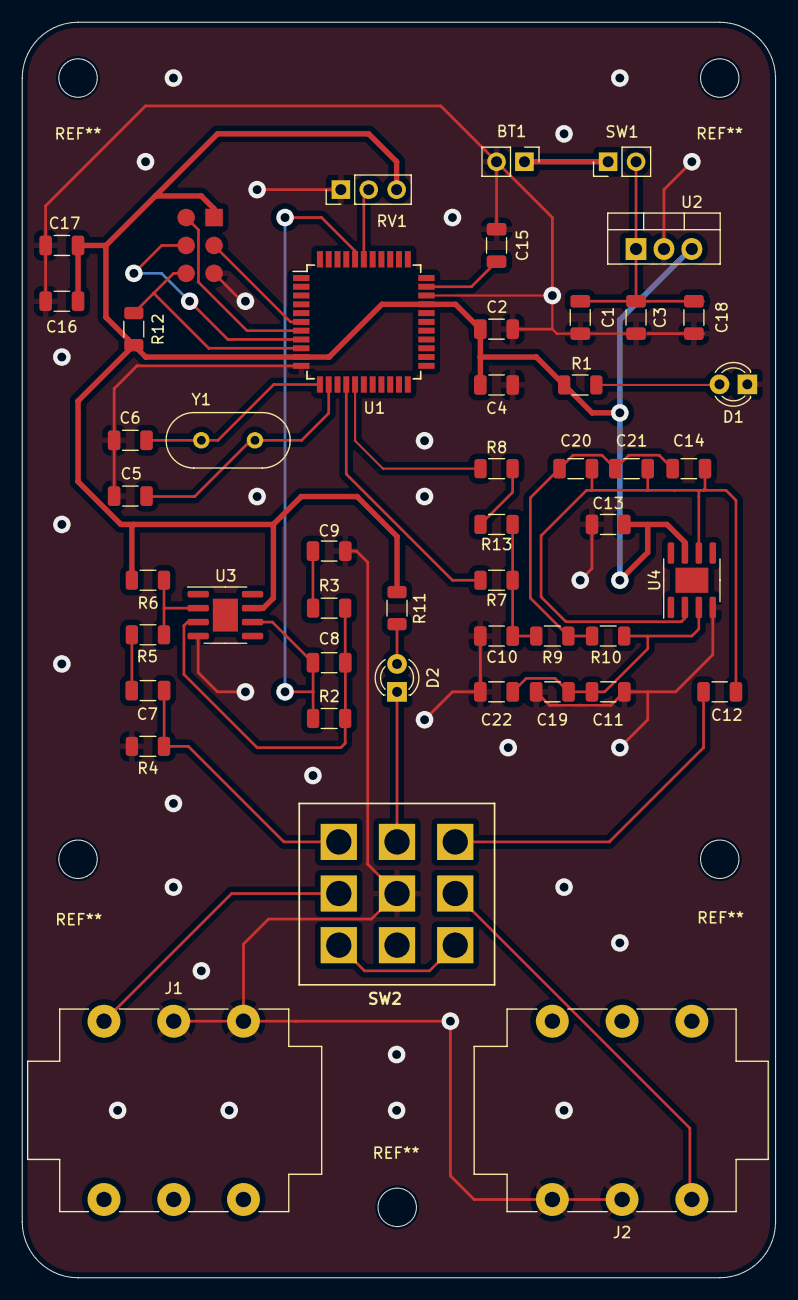
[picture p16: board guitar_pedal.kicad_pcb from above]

Board: 2 copper layers, 68.6 x 114.3 mm, 49 parts (0 on the bottom side), 32 nets.

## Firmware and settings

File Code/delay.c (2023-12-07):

/*
 * GuitarPedal.c
 *
 * Created: 12/01/2023
 * Author : Lynn
 * 
 * NOTE : ADC operates in single conversion, manual mode.
 */ 


#ifndef F_CPU
#define F_CPU 16000000UL    // 16MHz Clock Speed
#endif

 #include <avr/io.h>
// #include <util/delay.h>
#include <avr/interrupt.h>
#include <stdbool.h>

// defining the output PWM parameters
#define PWM_FREQ 0x00FF             // pwm frequency - 31.3KHz
#define PWM_MODE 0                  // Fast (1) or Phase Correct (0)
#define PWM_QTY 2                   // 2 PWMs in parallel

// Function definitions
long map(long x, long in_min, long in_max, long out_min, long out_max);
void switch_adc(void);
void pin_setup();
void timer_setup();
void adc_setup();

int main(void) {
    cli();
    pin_setup();
    timer_setup();
    adc_setup();
    sei(); // Enable global interrupts

    while (1) {}; // prevent program from ending
}
////////////////////////////////////////////////////////////////////////////
//                      Interrupt Service Routines                        //
////////////////////////////////////////////////////////////////////////////


// Timer1 interrupt
ISR(TIMER1_COMPA_vect) {
  36   // get ADC data
  37   unsigned int temp1 = ADCL; // you need to fetch the low byte first
  38   unsigned int temp2 = ADCH;
  50   
  51   // output high byte on OC1A
  52   OCR1AH = temp2 >> 8; // takes top 8 bits
  53   OCR1AL = temp2; // takes bottom 8 bits
  54   
  55   // output low byte on OC1B
  56   OCR1BH = temp1 >> 8;
  57   OCR1BL = temp1;
}

////////////////////////////////////////////////////////////////////////////
//                          HELPER FUNCTIONS                              //
////////////////////////////////////////////////////////////////////////////

void pin_setup(void){
    // Pins PD4 PD5 as output with PWM
    DDRD |= ((1<<DDB4) | (1<<DDB5));
    // Pins PA0 PA1 as input pins
    DDRA &= ~((1<<DDB0) | (1<<DDB1));
}

// Used to generate PWM signals
void timer_setup(void) {
  // setup PWM
  TCCR1A = (((PWM_QTY - 1) << 5) | 0x80 | (PWM_MODE << 1)); //
  TCCR1B = ((PWM_MODE << 3) | 0x11);                        // ck/1
  TIMSK1 = 0x20;                                            // interrupt on capture interrupt
  ICR1H = (PWM_FREQ >> 8);
  ICR1L = (PWM_FREQ & 0xff);
}

void adc_setup(void){   
  // setup ADC
  ADMUX = 0x60;   // left adjust, adc0, internal vcc
  ADCSRA = 0xe5;  // turn on adc, ck/32, auto trigger
  ADCSRB = 0x07;  // t1 capture for trigger
  DIDR0 = 0x01;   // turn off digital inputs for adc0
}

// Maps input value to one in given range, used to digitally amplify signal
long map(long x, long in_min, long in_max, long out_min, long out_max) {
  return (x - in_min) * (out_max - out_min) / (in_max - in_min) + out_min;
}

// // Bit manipulation -- reference
// DDRB |= (1 << DDB3);     // set pin 3 of Port B as output
// PORTB |= (1 << PB3);     // set pin 3 of Port B high
// PORTB &= ~(1 << PB3);    // set pin 3 of Port B low
// PORTB ^= (1 << PB3);   // toggles the state of the bit (XOR)m1111111

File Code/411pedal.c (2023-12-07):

/*
 * GuitarPedal.c
 *
 * Created: 12/01/2023
 * Author : Lynn
 * 
 * NOTE : ADC operates in single conversion, manual mode.
 */ 


#ifndef F_CPU
#define F_CPU 16000000UL    // 16MHz Clock Speed
#endif

 #include <avr/io.h>
// #include <util/delay.h>
#include <avr/interrupt.h>
#include <stdbool.h>

unsigned int ADC_low, ADC_high;
unsigned int POT0 = 0;
unsigned int upper_threshold, lower_threshold;
int input;
// int counter = 0;
// _Bool activeADC = false;

// Function definitions
long map(long x, long in_min, long in_max, long out_min, long out_max);
void switch_adc(void);
void pin_setup();
void timer_setup();
void adc_setup();

int main(void) {
    cli();
    pin_setup();
    timer_setup();
    adc_setup();
    sei(); // Enable global interrupts

    while (1) {}; // prevent program from ending
}
////////////////////////////////////////////////////////////////////////////
//                      Interrupt Service Routines                        //
////////////////////////////////////////////////////////////////////////////


// Timer1 interrupt
ISR(TIMER1_COMPA_vect) {
    // counter++;

    // if (counter >= 100) {
    //     switch_adc();
    // }

    ADC_low = 0;            // Always 0 to save space
    ADC_high = ADCH;
    
    // Determines clipping levels based on POT
    upper_threshold=map(POT0,0,4095,4095,2047);
    lower_threshold=map(POT0,0,4095,0000,2047);
    
    // Clips signal based on threshholds
    if (ADC_high>=upper_threshold) {
        ADC_high=upper_threshold;
    }
    else if (ADC_high<lower_threshold) {
        ADC_high=lower_threshold;
    }

    // Output
    input = ((ADC_high << 8) | ADC_low) + 0x8000; // make a signed 16b value

    OCR1AL = ((input + 0x8000) >> 8);       // convert to unsigned, send out high byte
    OCR1BL = input; // send out low byte    // PortD for the ATMega1284   
}

/*
// ADC Conversion Complete
ISR(ADC_vect) {
    if (!activeADC) {           // Update ADC_high/low (guitar line) if active channel is ADC0
        ADC_low = 0;            // Always 0 to save space
        ADC_high = ADCH;
    } else if (activeADC) {     // Update POT if active channel is ADC1
        POT0 = ADCH;
    }

    // Determines clipping levels based on POT
    upper_threshold=map(POT,0,4095,4095,2047);
    lower_threshold=map(POT,0,4095,0000,2047);
    
    // Clips signal based on threshholds
    if (ADC_high>=upper_threshold) {
        ADC_high=upper_threshold;
    }
    else if (ADC_high<lower_threshold) {
        ADC_high=lower_threshold;
    }

    // Output
    input = ((ADC_high << 8) | ADC_low) + 0x8000; // make a signed 16b value

    OCR1AL = ((input + 0x8000) >> 8);       // convert to unsigned, send out high byte
    OCR1BL = input; // send out low byte    // PortD for the ATMega1284
    
    // Conversion takes 13 seconds -> approx. 0.1 ms per conversion at 125KHz ADC freq.
    // Every 100 conversions = 1 ms/potentiometer reading
    if (++counter >= 100) {
        switch_adc();           // switch to ADC1 to read POT next conversion
        counter = 0;            // reset counter
    } else if (counter == 0) {
        switch_adc();           // switch back to ADC0
    }

    counter++;
    ADCSRA |= (1<<ADSC);        // Start next ADC conversion
}
*/

////////////////////////////////////////////////////////////////////////////
//                          HELPER FUNCTIONS                              //
////////////////////////////////////////////////////////////////////////////

void pin_setup(void){
    // Pins PD6 PD7 as output with PWM
    DDRD |= ((1<<DDB6) | (1<<DDB7));
    // Pins PA0 PA1 as input pins
    DDRA &= ~((1<<DDB0) | (1<<DDB1));
    DIDR0 = 0x01;   // turn off digital inputs for adc0

}

// Used to generate PWM signals
void timer_setup(void) {
    PRR0 &= ~(1<<PRTIM1);               // Enable TIMER1 module 
 
    // TCNT1 = 0x00;
    TCCR1B = (1<<WGM13) | (0<<WGM12);   // Phase correct, PWM waveform generation
    TCCR1A = (1<<WGM11) | (0<<WGM10);   // TOP = ICR1         
    TCCR1B = (1<<CS10);                 // CLK/1 = 16 MHz TIMER1
    TCCR1A = (1<<COM1A1);               // Set output to low level.
    TCCR1B = (1<<COM1B1);               //

    ICR1L = 0xFF;                        
    ICR1H = (0xFF >> 8);                // PWM frequency = TIMER1/(1*PRE*ICR1)
                                        // PWM Resolution = log2

    TIMSK1 = (1<<ICIE1);               // Enable TIMER1 capture interrupt
   
    // TCCR1A = (((PWM_QTY - 1) << 5) | 0x80 | (PWM_MODE << 1)); //
    // TCCR1B = ((PWM_MODE << 3) | 0x11);                        // CLK/1
    // ICR1H = (PWM_FREQ >> 8);             // PWM Frequency = 16 MHz/256 = 31.3 KHz
    // ICR1L = (PWM_FREQ & 0xFF);
}

void adc_setup(void){   
    ADCSRA |= (1<<ADPS2) | (1<<ADPS1) | (1<<ADPS0);     // CLK/128 = 125 KHz ADC frequency
    ADMUX |= (0<<REFS1) | (1<<REFS0);                   // AVCC with external capacitor at AREF pin
    ADMUX |= (1<<ADLAR);                                // Left aligned for 8 bit resolution
	ADMUX |= (0<<MUX0) | (0<<MUX1) | (0<<MUX2) | (0<<MUX3) | (0<<MUX4); // Select port ADC1
    PRR0 &= ~(1<<PRADC);     // Clear power reduction bit
    ADCSRB |= (1<<ADTS0) | (1<<ADTS1) | (1<<ADTS2); // Auto Triggered TIMER1 capture event
    ADCSRA |= (1<<ADEN);    // Enable ADC
	ADCSRA |= (1<<ADSC);    // Start first conversion
}

// Toggles LSB of ADMUX.MUX (switches between ADC0 and ADC1)
void switch_adc(void) {
    ADMUX ^= (1 << MUX0);
    activeADC = !activeADC;
}

// Maps input value to one in given range, used to digitally amplify signal
long map(long x, long in_min, long in_max, long out_min, long out_max) {
  return (x - in_min) * (out_max - out_min) / (in_max - in_min) + out_min;
}

// // Bit manipulation -- reference
// DDRB |= (1 << DDB3);     // set pin 3 of Port B as output
// PORTB |= (1 << PB3);     // set pin 3 of Port B high
// PORTB &= ~(1 << PB3);    // set pin 3 of Port B low
// PORTB ^= (1 << PB3);   // toggles the state of the bit (XOR)m1111111

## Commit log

2023-10-24 Add files via upload
    initial schematic
    [guitar_pedal.kicad_sch]
2023-10-26 Added input/output op-amp buffer stages.
    [guitar_pedal.kicad_sch]
2023-10-31 Added bypass circuitry. Made edits to buffer stages + LED
    [guitar_pedal.kicad_sch]
2023-11-02 Reorganized files. Added initial PCB. Added KiCad components. Some footprints added to schematic.
    [guitar_pedal.kicad_pcb, guitar_pedal.kicad_sch]
2023-11-02 Added somes caps and resistors
    [guitar_pedal.kicad_sch]
2023-11-02 Work In Progress Breadboard
    Prototype has its 5V voltage regulator, a temporary 10K potentiometer, and a temporary ATmega1284PU. Will likely switch to QFP of Atmega. Currently using LM386N op amp until TL972 op amp arrives. Als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
2023-11-02 Changed some incorrect voltages.
    Still needs to consolidate 2 individual op amps into the TL972IDR, dual op amp.
    [guitar_pedal.kicad_sch]
2023-11-09 Overall schematic layout updated. Minor changes to components.
    [guitar_pedal.kicad_sch]
2023-11-09 Updated components with footprints, added to PCB
    [guitar_pedal.kicad_pcb, guitar_pedal.kicad_sch]
2023-11-10 Added traces to power supply and AVR modules in PCB.
    [guitar_pedal.kicad_pcb, guitar_pedal.kicad_sch]
2023-11-13 Updated schematic to match available components.
    [guitar_pedal.kicad_sch]
2023-11-13 Updates to PCB layout, most connections except ground/power added.
    [guitar_pedal.kicad_pcb, guitar_pedal.kicad_sch]
2023-11-13 Schematic Notes.PDF added.
2023-11-13 Minor changes to PCB
    [guitar_pedal.kicad_pcb]
2023-11-14 Added remaining footprints to PCB, added ground plane and board edges.
    [guitar_pedal.kicad_pcb, guitar_pedal.kicad_sch]
2023-11-14 Added second layer. All connections on board. No errors in DRC, 200+ warnings.
    [guitar_pedal.kicad_pcb, guitar_pedal.kicad_sch]
2023-11-14 Updates to silkscreen
    [guitar_pedal.kicad_pcb]
2023-11-15 Gerber files generated for 2 layer board.
    [guitar_pedal-B_Cu.gbr, guitar_pedal-B_Mask.gbr, guitar_pedal-B_Paste.gbr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]
2023-11-15 4 layer PCB version added (won't be used). Fixed Gerber files for 2 layer board to include mask/silk.
    [guitar_pedal-B_Cu.gbr, guitar_pedal-B_Mask.gbr, guitar_pedal-B_Paste.gbr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]
2023-11-16 Design review changes. Vias added, fixed capacitors in output stage.
    [guitar_pedal.kicad_pcb, guitar_pedal.kicad_sch]
2023-11-16 Fixed cap series to parallel. Includes updated PCB and Gerber files
    [guitar_pedal-B_Cu.gbr, guitar_pedal-B_Mask.gbr, guitar_pedal-B_Paste.gbr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]
2023-11-16 Minor fixes to silkscreen
    [guitar_pedal-B_Cu.gbr, guitar_pedal-B_Mask.gbr, guitar_pedal-B_Paste.gbr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]
2023-11-22 Led test code
2023-11-22 Create ledtest.c
    test led on PIN21
2023-11-30 11-30.c -- timer interrupt based code for POT0
2023-12-03 Added timer logic to 1201.c
2023-12-03 Updated Code Plan.docx. Added Timer ISR.
2023-12-05 Deleted code files. Added ADC toggle to 411pedal.c
2023-12-05 Update 411pedal.c
    line 23 bool requires stdbool.h, not part of avr library, unsure if can be used.
    changed to:
    _Bool activeADC = false;
    line 133 assumed PRR0. power reduction register
    line 120 changed TICIE1 to ICIE1
    added function declerations line 28
    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
2023-12-06 Housing STL files added
    [Bottom Housing v4.stl, Upper housing v9.stl]
2023-12-06 Moved to TIMER1 interrupt
2023-12-07 Added Fusion files
    [Bottom Housing v4.f3d, Bottom Housing v4.stl, Upper housing v9.f3d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]
2023-12-07 Robs version
    [BottomHousing v2.stl, UpperHousing v1.stl]
2023-12-07 ADC trigger -> TIMER1. Delay.c added.
